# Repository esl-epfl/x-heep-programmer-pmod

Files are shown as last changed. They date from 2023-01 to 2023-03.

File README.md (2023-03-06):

# This repository contains the HEEP programmer PMOD
This PMOD pcb provides the following features:

1) An OpenOCD compatible JTAG programmer for debugging the RISC-V core
2) An 128 MBIT (Q)SPI flash chip as well as an [iceprog](https://github.com/YosysHQ/icestorm/tree/master/iceprog) compatible programmer for the flash (the programmer has been derived from [the excellent icebreaker board](https://github.com/icebreaker-fpga/icebreaker))
3) Two UARTs 

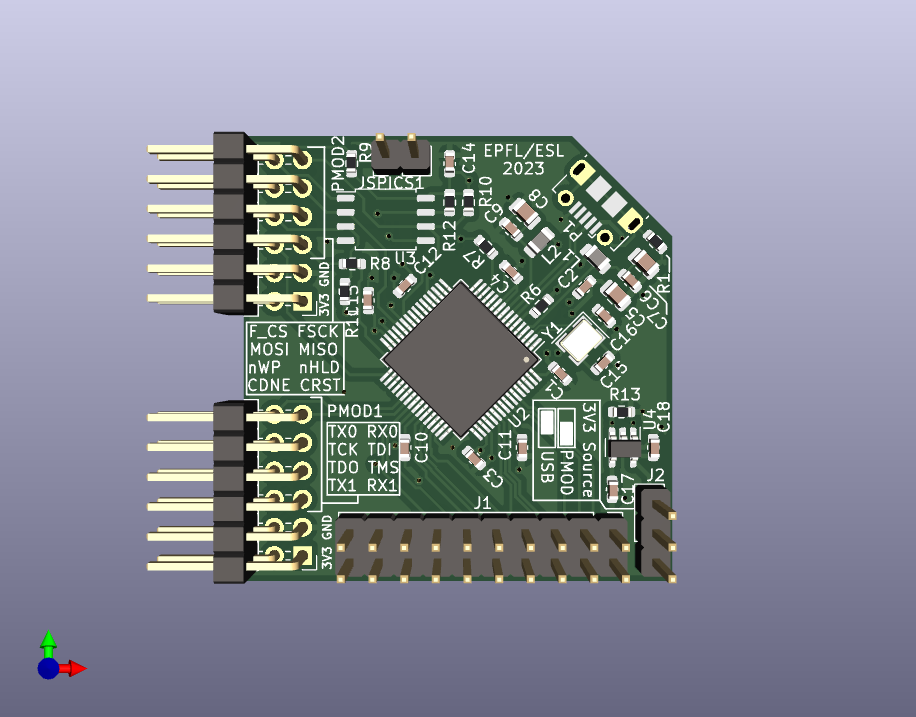
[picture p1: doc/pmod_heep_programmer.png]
PCB


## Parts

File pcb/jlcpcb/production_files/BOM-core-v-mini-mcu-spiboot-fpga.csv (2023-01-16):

Comment | Designator | Footprint | LCSC
10n | C17 | C_0603_1608Metric | C100042
51k | R1 | R_0603_1608Metric | C107231
30p | C15,C16 | C_0603_1608Metric | C113797
USB Micro | P1 | USB_Micro-B_Molex-105017-0001 | C132563
3.3u | C5 | C_0805_2012Metric | C159781
4.7u | C7,C8 | C_0805_2012Metric | C1779
10u | C18 | C_0603_1608Metric | C19702
12k 1% | R6 | R_0603_1608Metric | C22790
W25Q | U3 | SOIC-8_5.23x5.23mm_P1.27mm | C2613930
600n | L1,L2 | L_0805_2012Metric | C280244
100n | C1,C10,C11,C12,C13,C14,C2,C3,C4,C6,C9 | C_0603_1608Metric | C30926
2k2 | R8 | R_0603_1608Metric | C4190
FT4232HL | U2 | LQFP-64_10x10mm_P0.5mm | C56742
Crystal_GND24 | Y1 | Crystal_SMD_3225-4Pin_3.2x2.5mm | C9002
LP2985-3.3 | U4 | SOT-23-5 | C95414
10k | R10,R11,R12,R13,R7,R9 | R_0603_1608Metric | C98220
Conn_01x03 | J2 | PinHeader_1x03_P2.54mm_Vertical
Conn_02x10_Odd_Even | J1 | PinHeader_2x10_P2.54mm_Vertical
Conn_01x02 | JSPICS1 | PinHeader_1x02_P2.54mm_Vertical
Conn_02x06_Odd_Even | PMOD1 | PinHeader_2x06_P2.54mm_Horizontal
Conn_02x06_Odd_Even | PMOD2 | PinHeader_2x06_P2.54mm_Horizontal

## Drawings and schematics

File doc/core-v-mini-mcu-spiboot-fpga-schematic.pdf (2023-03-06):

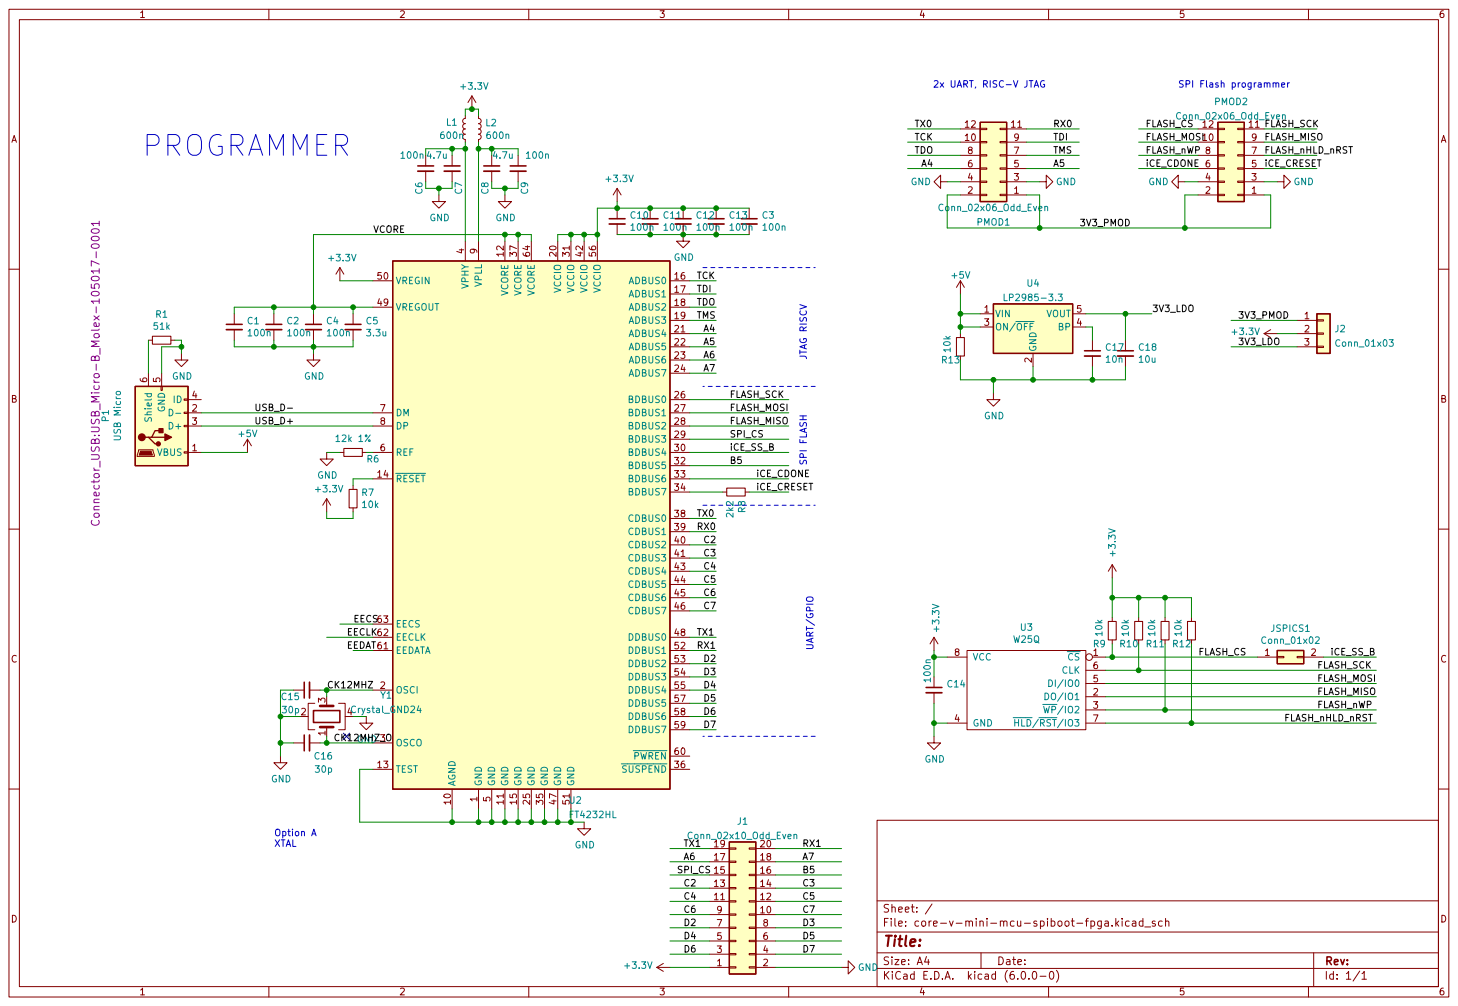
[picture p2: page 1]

2x UART, RISC-V JTAG UART/GPIO SPI FLASH JTAG RISCV

1 AGND 10 GND 11 VCORE 12 TEST 13 ~{RESET} 14 GND 15 ADBUS0 16 ADBUS1 17 ADBUS2 18 ADBUS3 19 OSCI 2 VCCIO 20 ADBUS4 21 ADBUS5 22 ADBUS6 23 ADBUS7 24 GND 25 BDBUS0 26 BDBUS1 27 BDBUS2 28 BDBUS3 29 OSCO 3 BDBUS4 30 VCCIO 31 BDBUS5 32 BDBUS6 33 BDBUS7 34 GND 35

4 CDBUS2 40 CDBUS3 41 VCCIO 42 CDBUS4 43 CDBUS5 44 CDBUS6 45 CDBUS7 46 GND 47 DDBUS0 48 VREGOUT 49 GND

5 VREGIN 50 GND 51 DDBUS1 52 DDBUS2 53 DDBUS3 54 DDBUS4 55 VCCIO 56 DDBUS5 57 DDBUS6 58 DDBUS7 59 REF 6 ~{PWREN} 60 EEDATA 61 EECLK 62 EECS 63 VCORE 64 DM 7 DP 8 VPLL

2 ON/~{OFF} 3 BP 4 VOUT 5 U4

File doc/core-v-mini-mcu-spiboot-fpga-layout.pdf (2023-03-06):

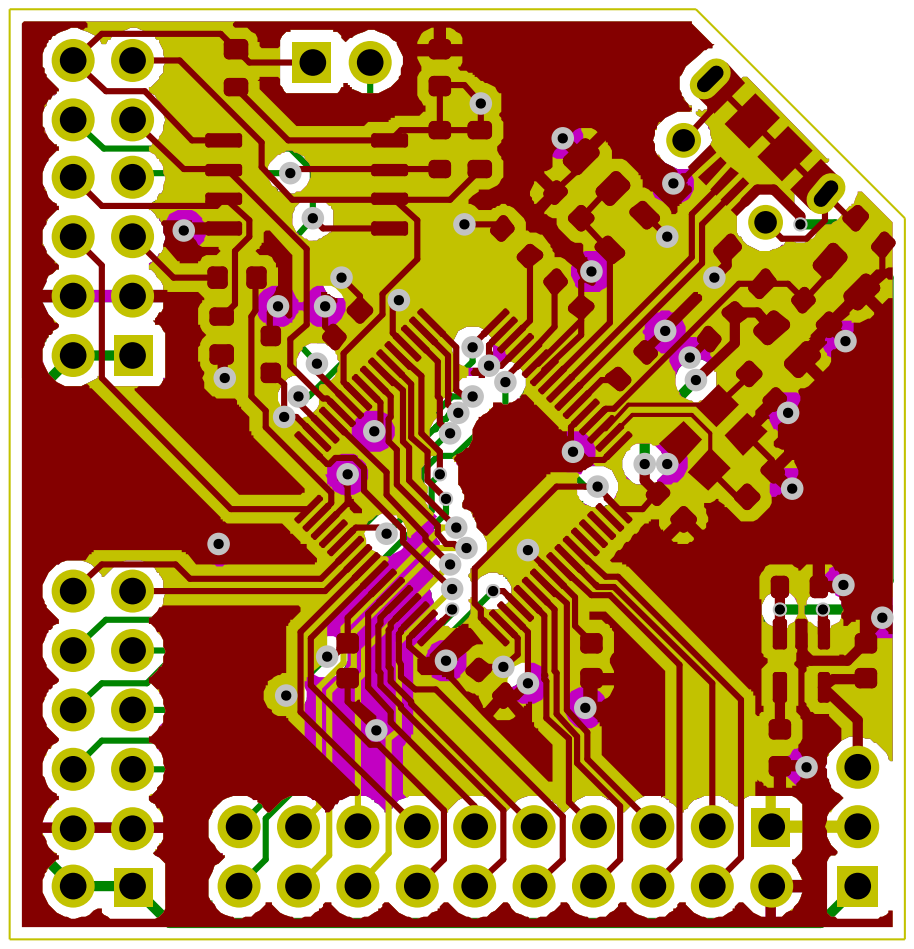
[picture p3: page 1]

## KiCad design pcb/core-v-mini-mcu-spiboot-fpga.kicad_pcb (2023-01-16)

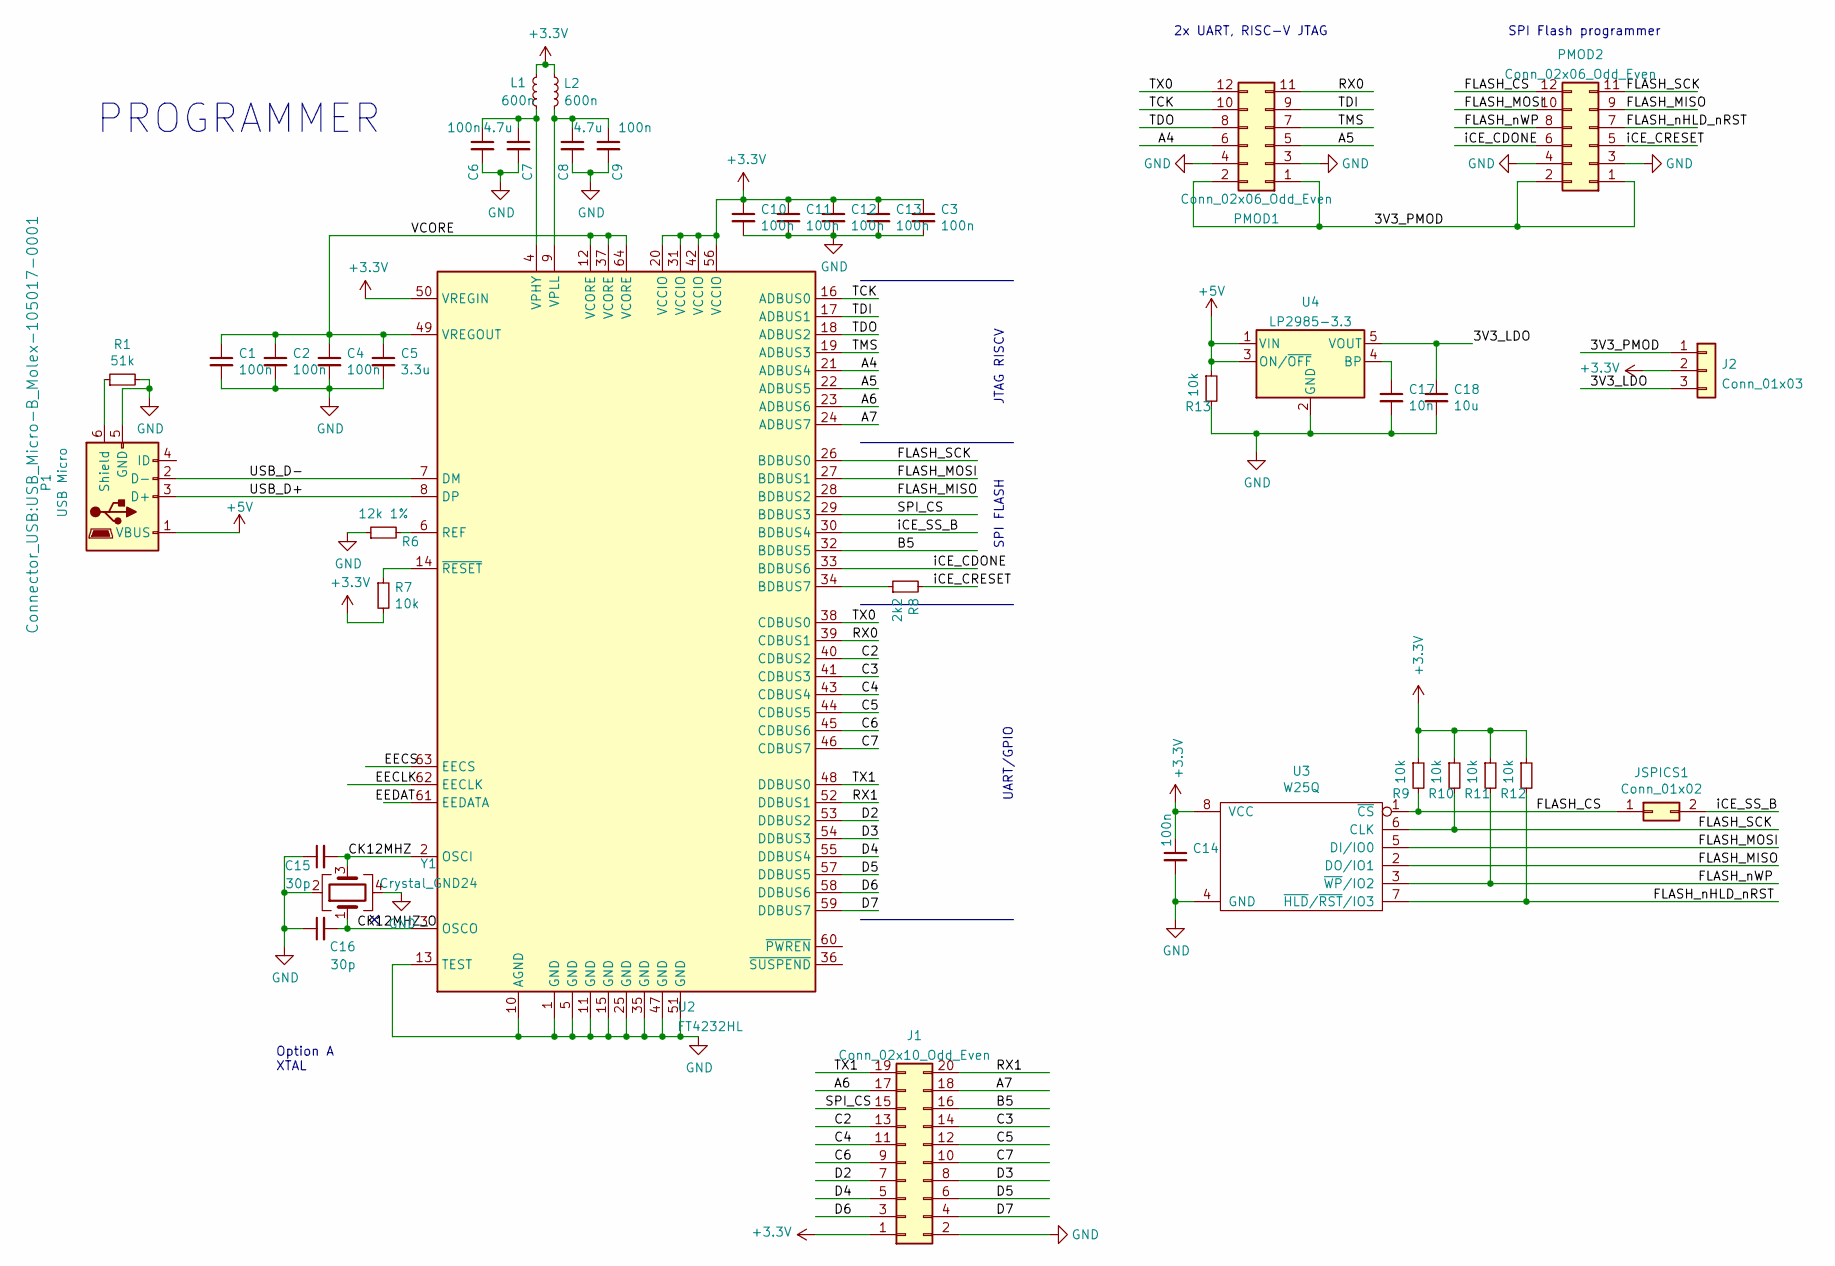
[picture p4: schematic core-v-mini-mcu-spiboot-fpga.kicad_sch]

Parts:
C1, C2, C3, C4, C6, C9, C10, C11, C12, C13, C14: 100n; C_0603_1608Metric; Mouser Part Number 80-C0805C104Z3V; Digikey Part Number 399-9158-1-ND
C5: 3.3u; C_0805_2012Metric; Mouser Part Number 80-C0805C335K8P; Digikey Part Number 399-3129-1-ND
C7, C8: 4.7u; C_0805_2012Metric; Mouser Part Number 80-C0805C475K9P; Digikey Part Number 399-3134-1-ND
C15, C16: 30p; C_0603_1608Metric; Mouser Part Number 80-C0805C104Z3V; Digikey Part Number 399-9158-1-ND
C17: 10n; C_0603_1608Metric; Mouser Part Number 80-C0805C104Z3V; Digikey Part Number 399-9158-1-ND
C18: 10u; C_0603_1608Metric; Mouser Part Number 80-C0805C104Z3V; Digikey Part Number 399-9158-1-ND
J1: Conn_02x10_Odd_Even; PinHeader_2x10_P2.54mm_Vertical
J2: Conn_01x03; PinHeader_1x03_P2.54mm_Vertical
JSPICS1: Conn_01x02; PinHeader_1x02_P2.54mm_Vertical; Digikey Part Number 2057-PH1-02-UA-ND
L1, L2: 600n; L_0805_2012Metric; Digikey Part Number 2035-1293-1-ND
P1: USB Micro; USB_Micro-B_Molex-105017-0001; Mouser Part Number 538-105017-0001; Digikey Part Number WM1399CT-ND
PMOD1, PMOD2: Conn_02x06_Odd_Even; PinHeader_2x06_P2.54mm_Horizontal
R1: 51k; R_0603_1608Metric; Mouser Part Number 660-RK73B1JTTD513J; Digikey Part Number 2019-RK73B1JTTD513JCT-ND
R6: 12k 1%; R_0603_1608Metric; Mouser Part Number 652-CR0603FX-1202ELF; Digikey Part Number 118-CR0603-FX-1202ELFCT-ND
R7, R9, R10, R11, R12, R13: 10k; R_0603_1608Metric; Mouser Part Number 667-ERJ-3GEYJ103V; Digikey Part Number P10KGCT-ND
R8: 2k2; R_0603_1608Metric; Mouser Part Number 667-ERJ-3GEYJ222V; Digikey Part Number P2.2KGCT-ND
U2: FT4232HL; LQFP-64_10x10mm_P0.5mm
U3: W25Q; SOIC-8_5.23x5.23mm_P1.27mm; Mouser Part Number 454-W25Q128JVSIMTR; Digikey Part Number W25Q128JVSIMCT-ND
U4: LP2985-3.3; SOT-23-5
Y1: Crystal_GND24; Crystal_SMD_3225-4Pin_3.2x2.5mm

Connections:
+3V3: C3.1, C10.1, C11.1, C12.1, C13.1, C14.1, J1.1, J2.2, L1.1, L2.1, R7.2, R9.1, R10.1, R11.1, R12.1, U2.20 (VCCIO), U2.31 (VCCIO), U2.42 (VCCIO), U2.50 (VREGIN), U2.56 (VCCIO), U3.8 (VCC)
+5V: P1.1 (VBUS), R13.1, U4.1 (VIN), U4.3 (ON/~OFF)
/3V3_LDO: C18.1, J2.3, U4.5 (VOUT)
/3V3_PMOD: J2.1, PMOD1.1, PMOD1.2, PMOD2.1, PMOD2.2
/A4: PMOD1.6, U2.21 (ADBUS4)
/A5: PMOD1.5, U2.22 (ADBUS5)
/A6: J1.17, U2.23 (ADBUS6)
/A7: J1.18, U2.24 (ADBUS7)
/B5: J1.16, U2.32 (BDBUS5)
/C2: J1.13, U2.40 (CDBUS2)
/C3: J1.14, U2.41 (CDBUS3)
/C4: J1.11, U2.43 (CDBUS4)
/C5: J1.12, U2.44 (CDBUS5)
/C6: J1.9, U2.45 (CDBUS6)
/C7: J1.10, U2.46 (CDBUS7)
/CK12MHZ: C15.2, U2.2 (OSCI), Y1.3
/CK12MHZ_O: C16.2, U2.3 (OSCO), Y1.1
/D2: J1.7, U2.53 (DDBUS2)
/D3: J1.8, U2.54 (DDBUS3)
/D4: J1.5, U2.55 (DDBUS4)
/D5: J1.6, U2.57 (DDBUS5)
/D6: J1.3, U2.58 (DDBUS6)
/D7: J1.4, U2.59 (DDBUS7)
/EECLK: U2.62 (EECLK)
/EECS: U2.63 (EECS)
/FLASH_CS: JSPICS1.1, PMOD2.12, R9.2, U3.1 (~CS)
/FLASH_MISO: PMOD2.9, U2.28 (BDBUS2), U3.2 (DO/IO1)
/FLASH_MOSI: PMOD2.10, U2.27 (BDBUS1), U3.5 (DI/IO0)
/FLASH_SCK: PMOD2.11, R10.2, U2.26 (BDBUS0), U3.6 (CLK)
/FLASH_nHLD_nRST: PMOD2.7, R12.2, U3.7 (~HLD/~RST/IO3)
/FLASH_nWP: PMOD2.8, R11.2, U3.3 (~WP/IO2)
/RX0: PMOD1.11, U2.39 (CDBUS1)
/RX1: J1.20, U2.52 (DDBUS1)
/SPI_CS: J1.15, U2.29 (BDBUS3)
/TCK: PMOD1.10, U2.16 (ADBUS0)
/TDI: PMOD1.9, U2.17 (ADBUS1)
/TDO: PMOD1.8, U2.18 (ADBUS2)
/TMS: PMOD1.7, U2.19 (ADBUS3)
/TX0: PMOD1.12, U2.38 (CDBUS0)
/TX1: J1.19, U2.48 (DDBUS0)
/USB_D+: P1.3 (D+), U2.8 (DP)
/USB_D-: P1.2 (D-), U2.7 (DM)
/VCORE: C1.1, C2.1, C4.1, C5.1, U2.12 (VCORE), U2.37 (VCORE), U2.49 (VREGOUT), U2.64 (VCORE)
/iCE_CDONE: PMOD2.6, U2.33 (BDBUS6)
/iCE_CRESET: PMOD2.5, R8.2
/iCE_SS_B: JSPICS1.2, U2.30 (BDBUS4)
GND: C1.2, C2.2, C3.2, C4.2, C5.2, C6.2, C7.2, C8.2, C9.2, C10.2, C11.2, C12.2, C13.2, C14.2, C15.1, C16.1, C17.2, C18.2, J1.2, P1.5 (GND), PMOD1.3, PMOD1.4, PMOD2.3, PMOD2.4, R1.2, R6.1, R13.2, U2.1 (GND), U2.5 (GND), U2.10 (AGND), U2.11 (GND), U2.13 (TEST), U2.15 (GND), U2.25 (GND), U2.35 (GND), U2.47 (GND), U2.51 (GND), U3.4 (GND), U4.2 (GND), Y1.2, Y1.4
unnamed: C6.1, C7.1, L1.2, U2.4 (VPHY)
unnamed: C8.1, C9.1, L2.2, U2.9 (VPLL)
unnamed: C17.1, U4.4 (BP)
unnamed: P1.6 (Shield), R1.1
unnamed: R6.2, U2.6 (REF)
unnamed: R7.1, U2.14 (~RESET)
unnamed: R8.1, U2.34 (BDBUS7)

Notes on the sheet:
SPI FLASH
SPI Flash programmer
JTAG RISCV
UART/GPIO
Option A XTAL
2x UART, RISC-V JTAG
PROGRAMMER

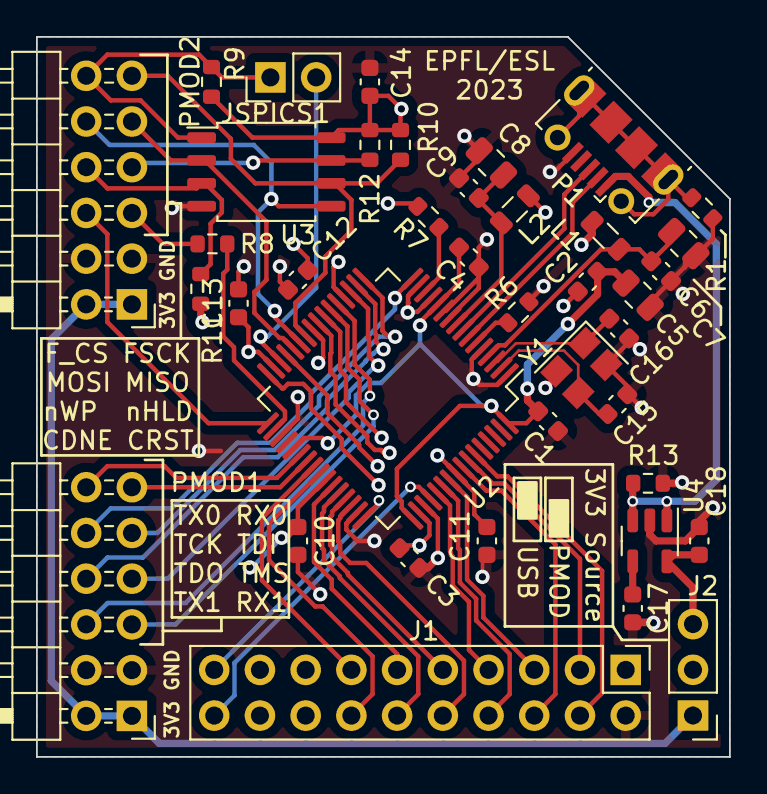
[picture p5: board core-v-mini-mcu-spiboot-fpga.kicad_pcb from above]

Board: 4 copper layers, 38.5 x 40.0 mm, 39 parts (0 on the bottom side), 52 nets.

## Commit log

2022-06-17 pcb added
    [core-v-mini-mcu-spiboot-fpga.kicad_pcb, core-v-mini-mcu-spiboot-fpga.kicad_sch]
2022-06-21 Revision 2: Converted to the available 56 pin QFN package, added missing oscillator
    [core-v-mini-mcu-spiboot-fpga.kicad_pcb, core-v-mini-mcu-spiboot-fpga.kicad_sch]
2022-06-30 QFN version
    [core-v-mini-mcu-spiboot-fpga.kicad_pcb, core-v-mini-mcu-spiboot-fpga.kicad_sch]
2023-01-16 Programmer reverted to LQFP package, production files for JLCPCB order added.
    [BOM-core-v-mini-mcu-spiboot-fpga.csv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]
